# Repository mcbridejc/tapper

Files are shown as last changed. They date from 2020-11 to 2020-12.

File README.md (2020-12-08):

# Tapper

A flexible way to build well-packaged touch-screen based devices with 
STM32 nucleo-32 boards. 

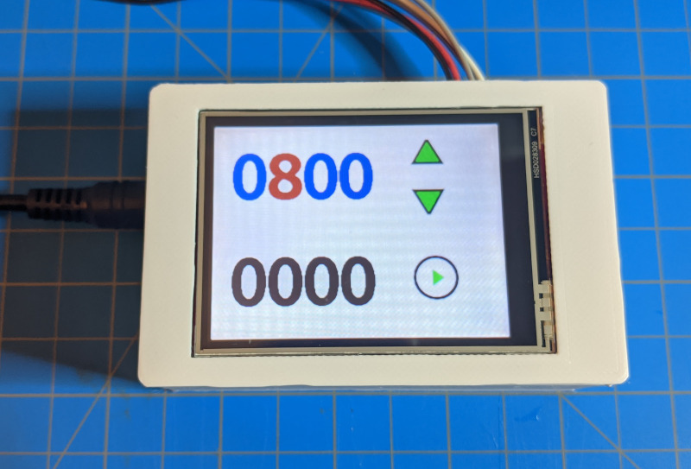
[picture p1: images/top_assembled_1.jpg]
Tapper


## Introduction

I wanted a quick and easy way to bring up any kind of touch screen based 
device that wasn't a one-off jumble of wires and/or breadboards.
My main requirements are that it needs a case, and it needs to be connecterized. 
I wanted to keep some flexibility though, because you can't quite predict which 
pins you need to wire out to which connectors next time, and you might need a 
bit of extra circuitry. 

On tapper, the connector IOs are connected only to test points. 
The MCU pins are also wired out to test points. To customize for a particular 
application, just solder jumper wires to connect as neded. 
There's also a small amount of 0.1" pitch hole array for prototyping; enough 
to fit a couple chips and discretes, e.g. using SMT to DIP adapters.

PDF schematic can be found [here](pcb/Tapper_rev2_schematic.pdf).

Bill of materials can be found [here](pcb/BOM.xlsx).

Gerbers can be found under github releases, if you want to build one!

## Powering 

The Tapper has a 5.5x2.1mm barrel connector for power input (7V min, up to about 
12-ish V<sup>[1](#maxvolts)</sup>), or, optionally it can be powered via the USB connector if you
don't need any voltage higher than 5V. 
For my initial application I needed a higher voltage for motor control, so
the tapper includes a linear regulator to generare the 5V input for the nucleo.
Thanks to the diode-or on the nucleo-32 board, it is safe to provide both USB 
power and an extra VIN. 

## Connectors

There are three 6-pin JST SH connectors. [Pre-made pigtails](https://www.digikey.com/en/products/detail/trinamic-motion-control-gmbh/CABLE-PH06/9381902) 
can be used to connect to these. Each connector has a ground pin, a power pin 
which can be connected to 3.3V, 5V, or VIN -- selected by solder bridge -- and
four IO pins which are connected to testpoints. These can be connected by 
wires soldered to either the MCU breakout testpoints or to 
a circuit on the prototype pad array.

## STM32 Development Board

Tapper is designed for the [Nucleo-G431KB](https://www.st.com/en/evaluation-tools/nucleo-g431kb.html),
but since all of the Nucleo-32 boards have a compatible pinout -- at least 
I'm pretty sure they do, double check -- it should be easy to use a different
family of STM32 MCU. The ST Nucleo boards come with a built-in ST-LINK USB
programmer/debugger, which also provides a virtual COM port connected to the
USART on your target device.

### Nucleo board modifications

**Important: You probably need to modify your Nucleo board!**

Remove SB2 and SB3. These short PA15 to PA6 and PB7 to PA6 -- why ST thought
it was a good idea to ship development boards with jumpers shorting their 
IOs is beyond me, but removing them is the first thing I do on every nucleo 
board.

Short SB11. This connects PF1 to the IO header, and is needed to drive the 
display DC pin. Without shorting this solder bridge, the display will not
update.

## Enclosure

The enclosure can be 3D printed. Heated threaded inserts are used to provide
solid mounting points for the electronicson the top cover. See the 
[Bill of Materials](pcb/BOM.xls). It uses flexible retaining clips to hold
the two parts of the enclosure together, and this works....OK. If the print 
isn't dialed in just right, the top cover might not sit perflectly tight; 
functional but disappointing. At some point, I may redesign it to use some 
longer screws that go all the way through the enclosure. It was the first 
time I tried printing such a thing, and it was a worthwhile experiment, anyway.

### Top Model

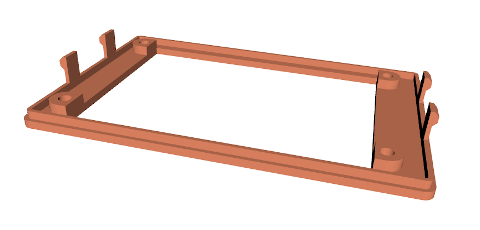
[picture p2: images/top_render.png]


[3D Model - STEP](enclosure/tapper_enclosure_top.step)

[3D Model - STL](enclosure/tapper_enclosure_top.stl)

### Bottom Model

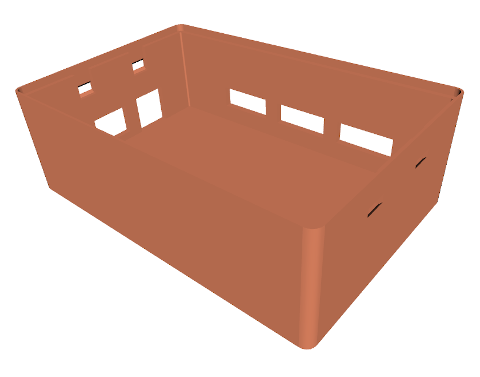
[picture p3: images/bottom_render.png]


[3D Model - STEP](enclosure/tapper_enclosure_bottom.step)

[3D Model - STL](enclosure/tapper_enclosure_bottom.stl)

## Example Software

This [spincoater controller](https://github.com/mcbridejc/spincoater-controller) project uses the Tapper board, and provides an
example software project using the [modm](https://modm.io) C++ peripheral library, which
I highly recommend for STM32 projects.

## Photos

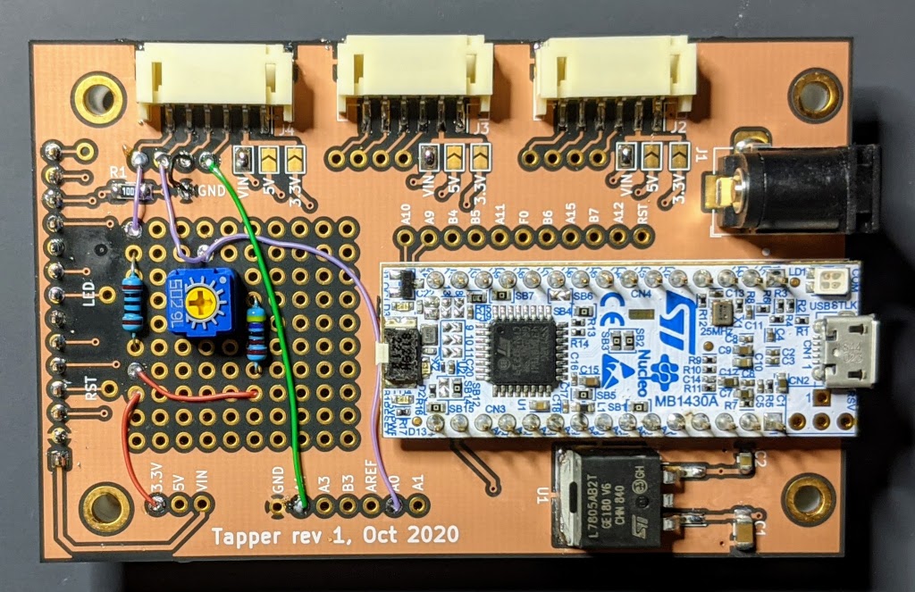
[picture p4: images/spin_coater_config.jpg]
Bareboard with spincoater wiring


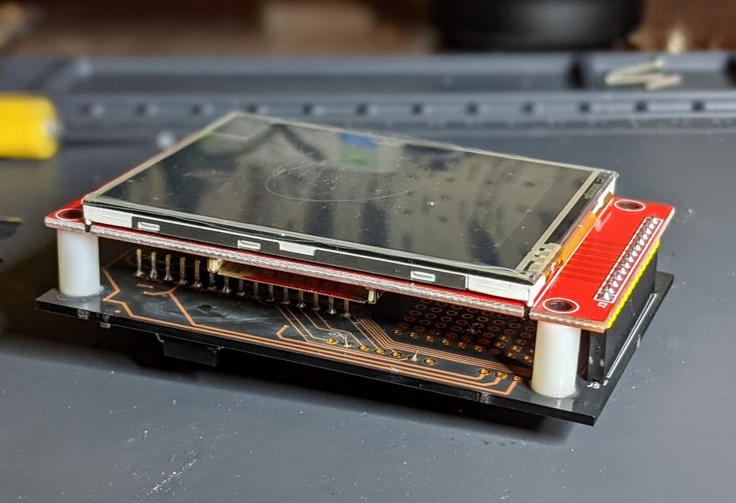
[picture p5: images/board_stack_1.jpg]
Board stackup with display


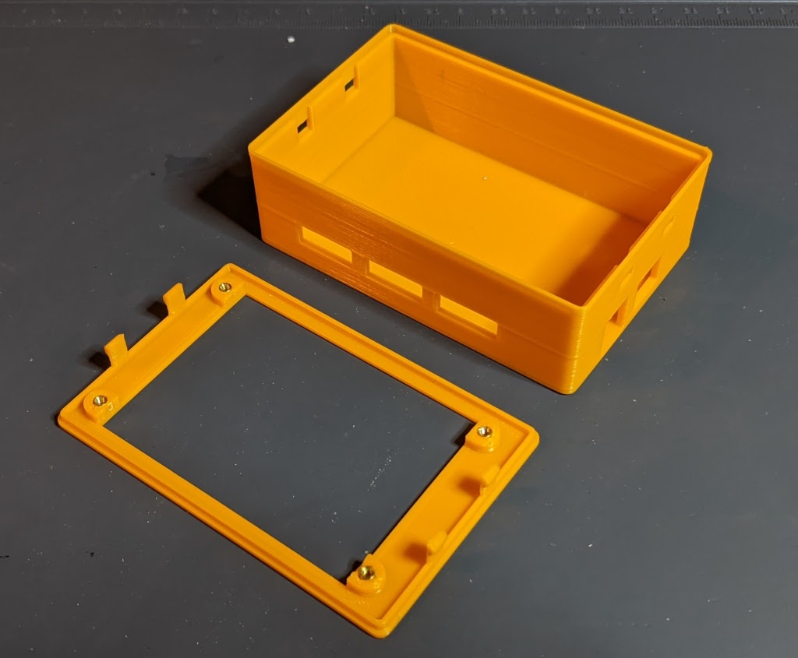
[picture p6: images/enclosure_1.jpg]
Enclosure


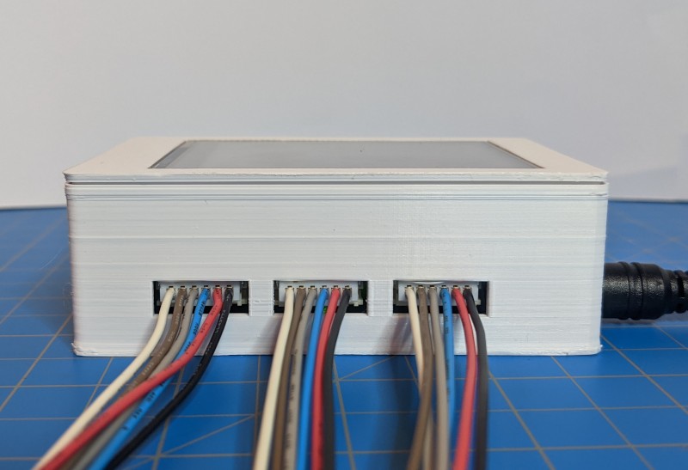
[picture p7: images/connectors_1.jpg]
IO connectors


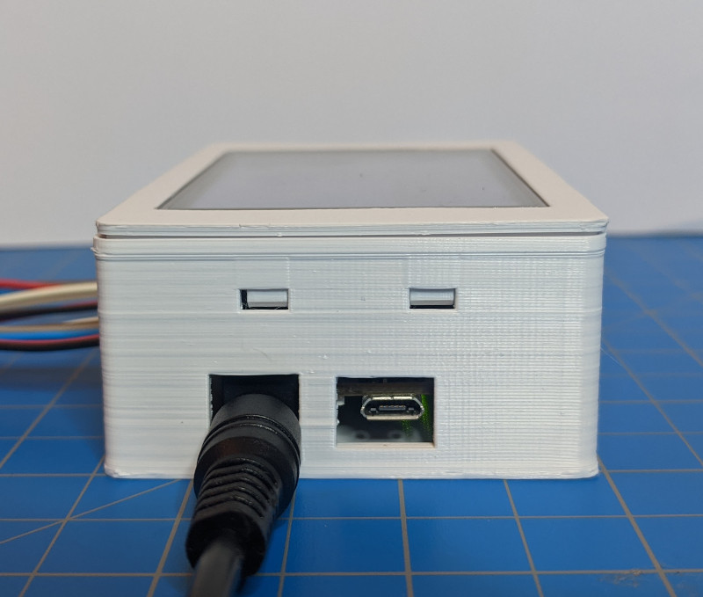
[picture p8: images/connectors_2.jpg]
Power and USB connectors


## Revision History

### Revision 2 (Nov 2020)

Fix a few mistakes, including: 

- Add pull-up to display reset pin
- Power connection points labeled wrong in silkscreen (3.3V and VIN swapped, yikes)
- One mounting hole position off by 0.5mm

### Revision 1 (Oct 2020)

First prototype design. 

# Footnotes

<b id="maxvolts">1:</b>The max voltage will be limited by the thermal dissipation of the 
linear regulator, and will depend on how much power is drawn from the 5V rail. If 
it gets too hot to touch, it might be time to consider lowering your input voltage!

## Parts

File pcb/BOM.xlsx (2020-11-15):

Digikey
RefDes | Mfg Part Number | Qty | Description | Unit Cost | Total Cost
J1 | 839-1514-ND‎ | 1 | Barrel Jack | $0.97 | $0.97
J2, J3, J4 | S6B-PH-SM4-TB(LF)(SN) | 3 | JST PH connectors | $0.72 | $2.16
J5 | PPPC141LFBN-RC | 1 | 14 pos header, female | $0.95 | $0.95
U1 | L7805ABD2T-TR | 1 | Linear regulator, 5V | $0.66 | $0.66
C1 | CL31A106KBHNNNE | 1 | 10uF 1206 | $0.25 | $0.25
C2 | CL21B105KAFNNNG | 1 | 1uF 805 | $0.03 | $0.03
H1-H4 | 960110042 | 4 | Spacers, 11mm | $0.25 | $1.00
R1-R2 | ERJ-8ENF1002V | 2 | 10k 1206 | $0.03 | $0.06
A1 | Nucleo-G431KB | 1 | STM32 Dev board | $13.00 | $13.00
 | 1460-1297-ND | 3 | 6-pin PH pigtail | $1.06 | $3.18
 |  |  |  |  | $0.00
McMaster | 1460-1297-ND |  |  |  | $0.00
NA | 94459A110 | 4 | Heat inserts M2 | $0.17 | $0.68
 | 92000A022 | 4 | m2x16mm screw | $0.07 | $0.28
 |  |  |  |  | $0.00
Amazon |  |  |  |  | $0.00
NA | Hiletgo ILI9341 2.8” | 1 | LCD display with touch panel | $14.00 | $14.00
Oshpark
NA | PCBs | 1 | basic oshpark price | 12.33333333 | $12.33
 |  |  |  | Total: | $49.55

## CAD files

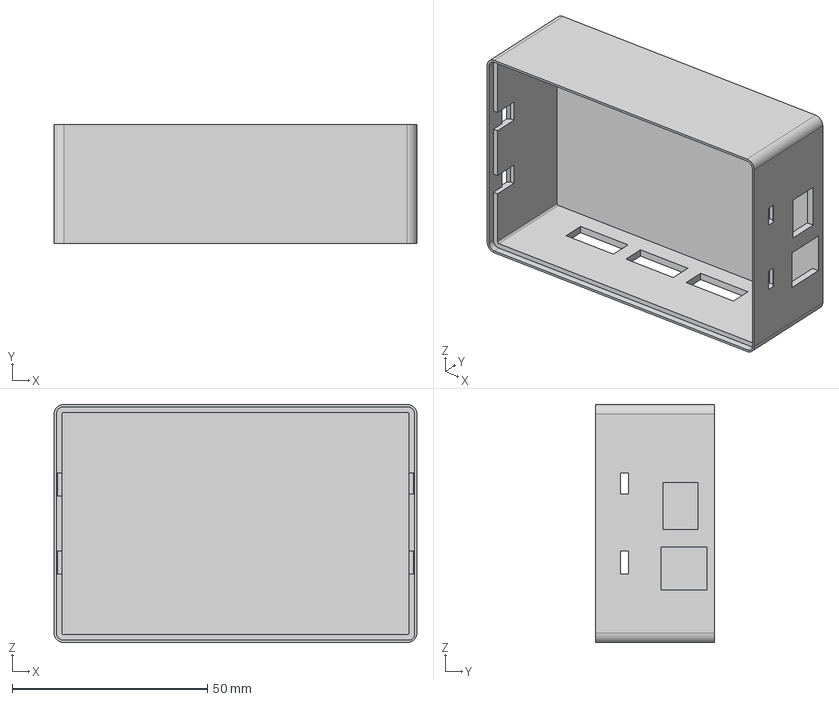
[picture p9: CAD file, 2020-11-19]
enclosure/tapper_enclosure_bottom.step
93.0 x 30.6 x 61.0 mm

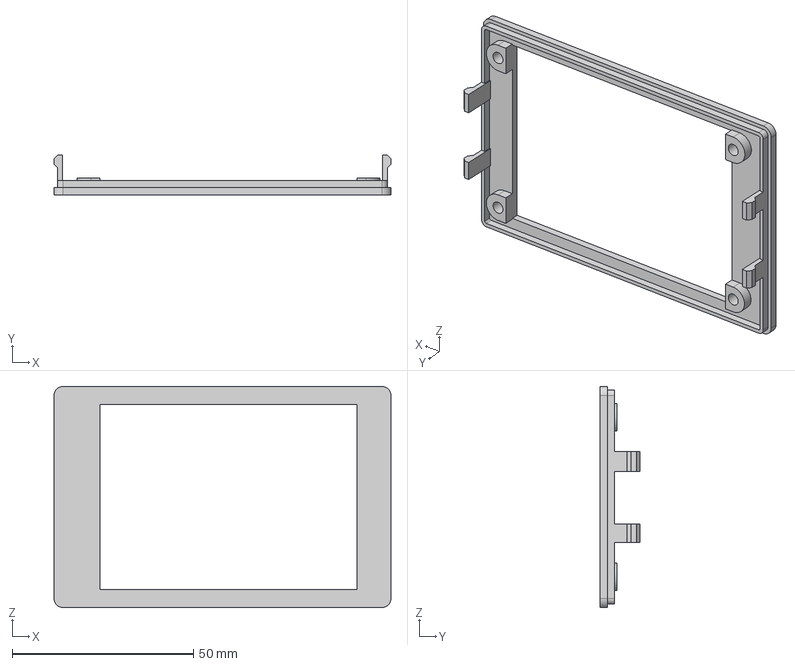
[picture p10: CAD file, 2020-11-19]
enclosure/tapper_enclosure_top.step
93.0 x 11.0 x 61.0 mm

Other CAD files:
enclosure/tapper_enclosure_bottom.stl
enclosure/tapper_enclosure_top.stl

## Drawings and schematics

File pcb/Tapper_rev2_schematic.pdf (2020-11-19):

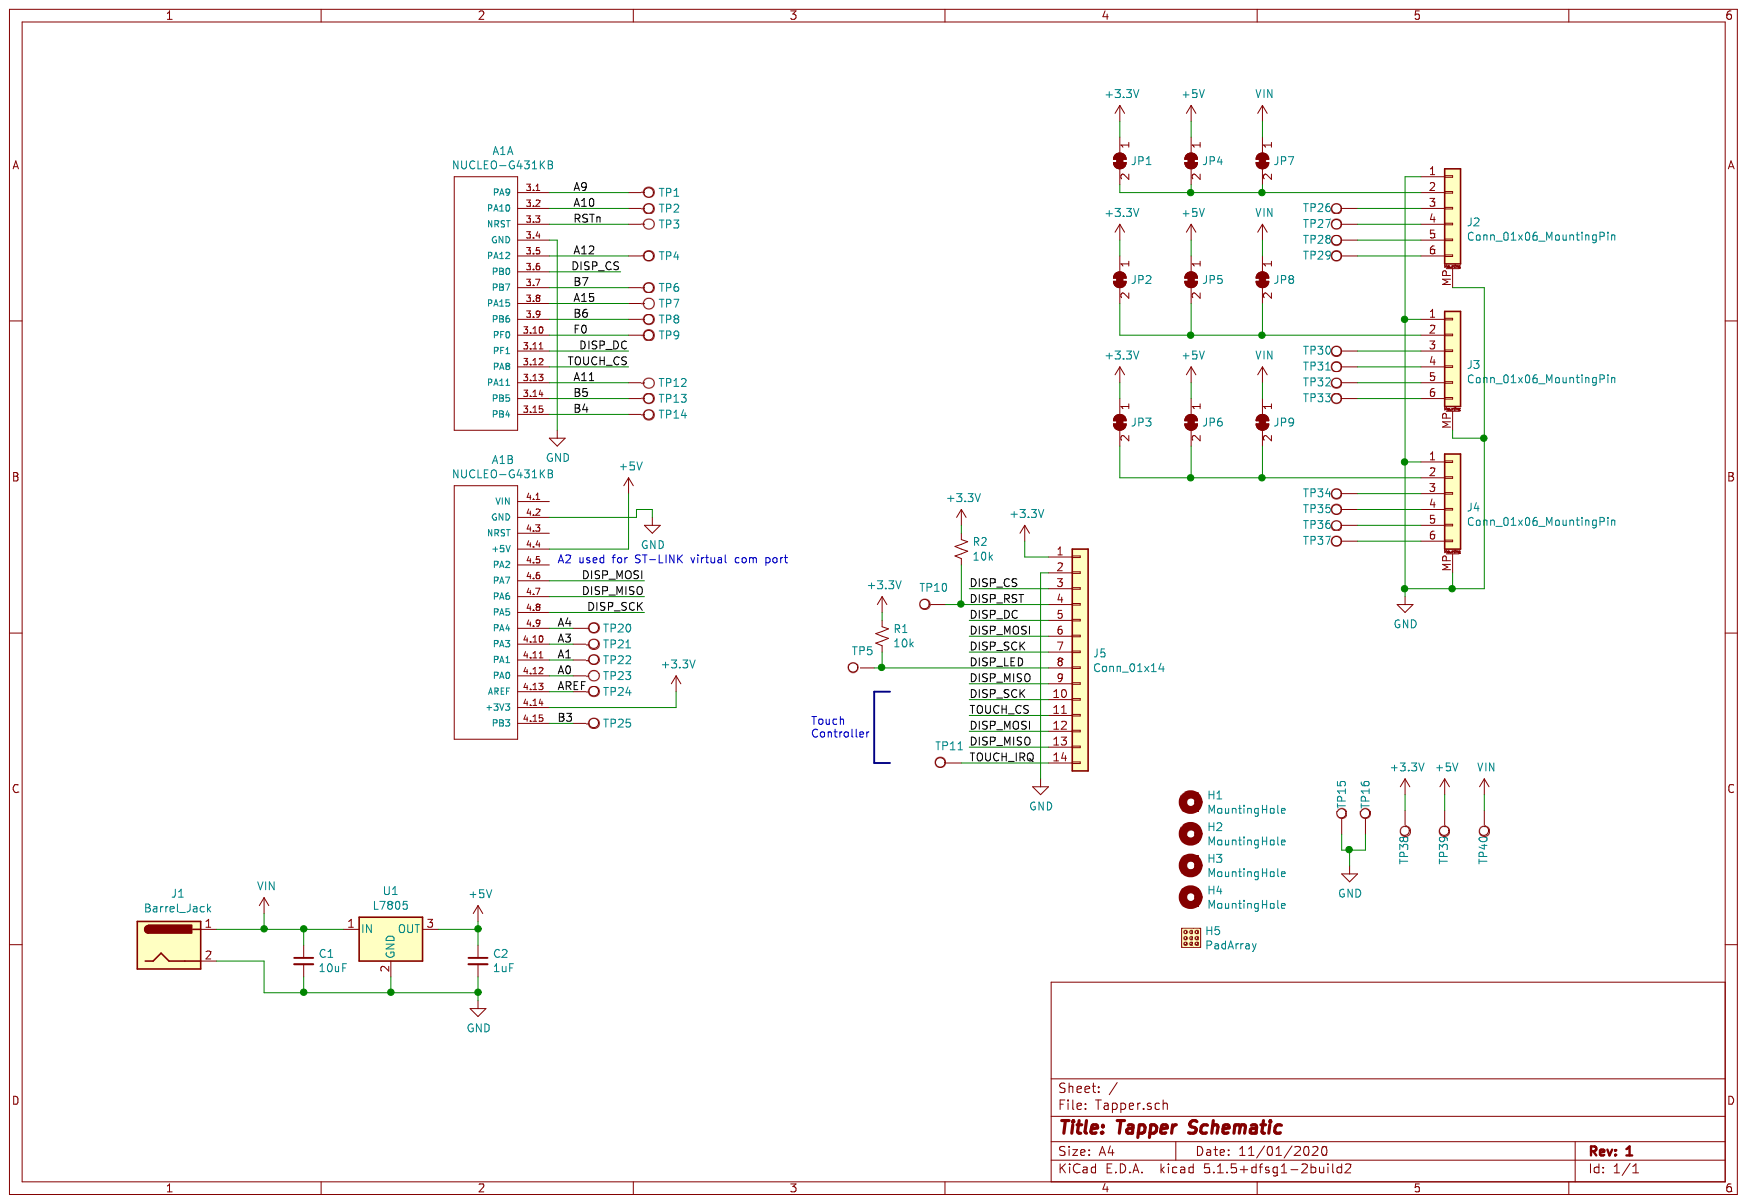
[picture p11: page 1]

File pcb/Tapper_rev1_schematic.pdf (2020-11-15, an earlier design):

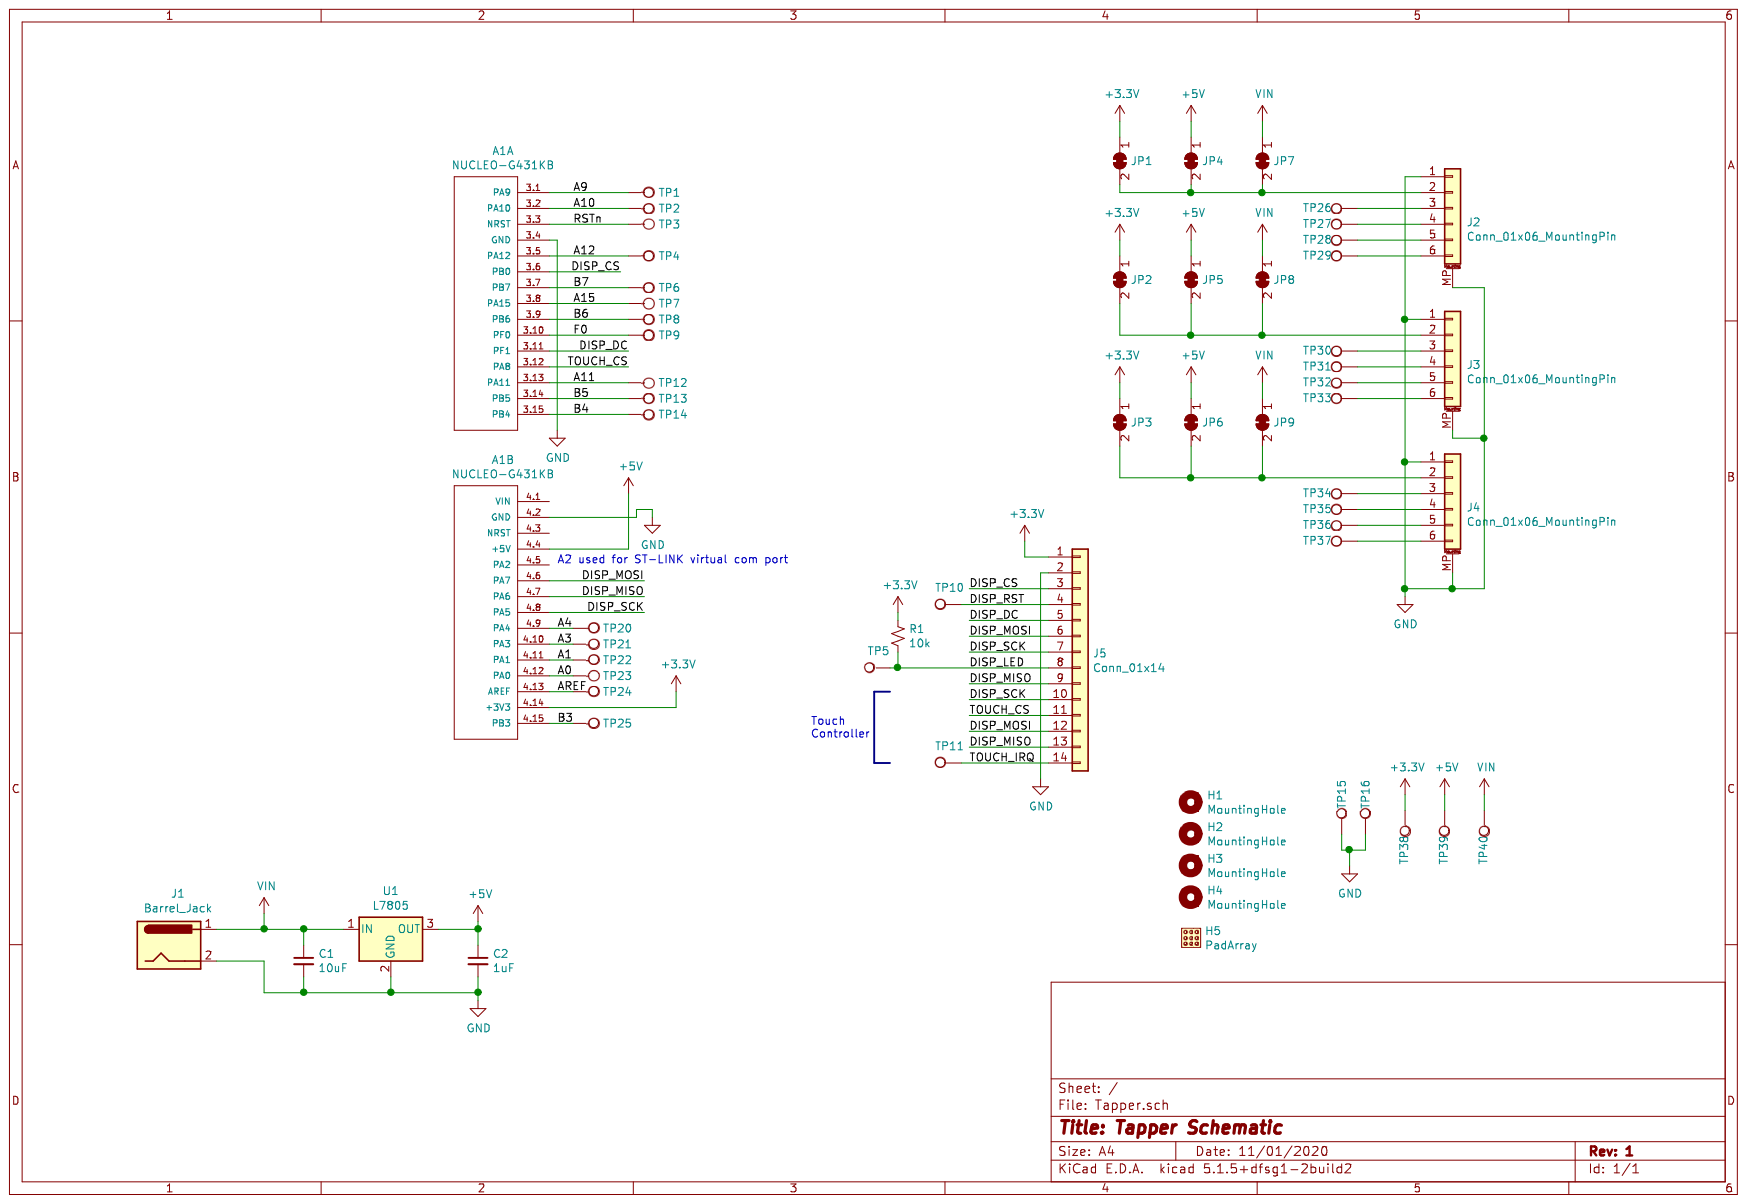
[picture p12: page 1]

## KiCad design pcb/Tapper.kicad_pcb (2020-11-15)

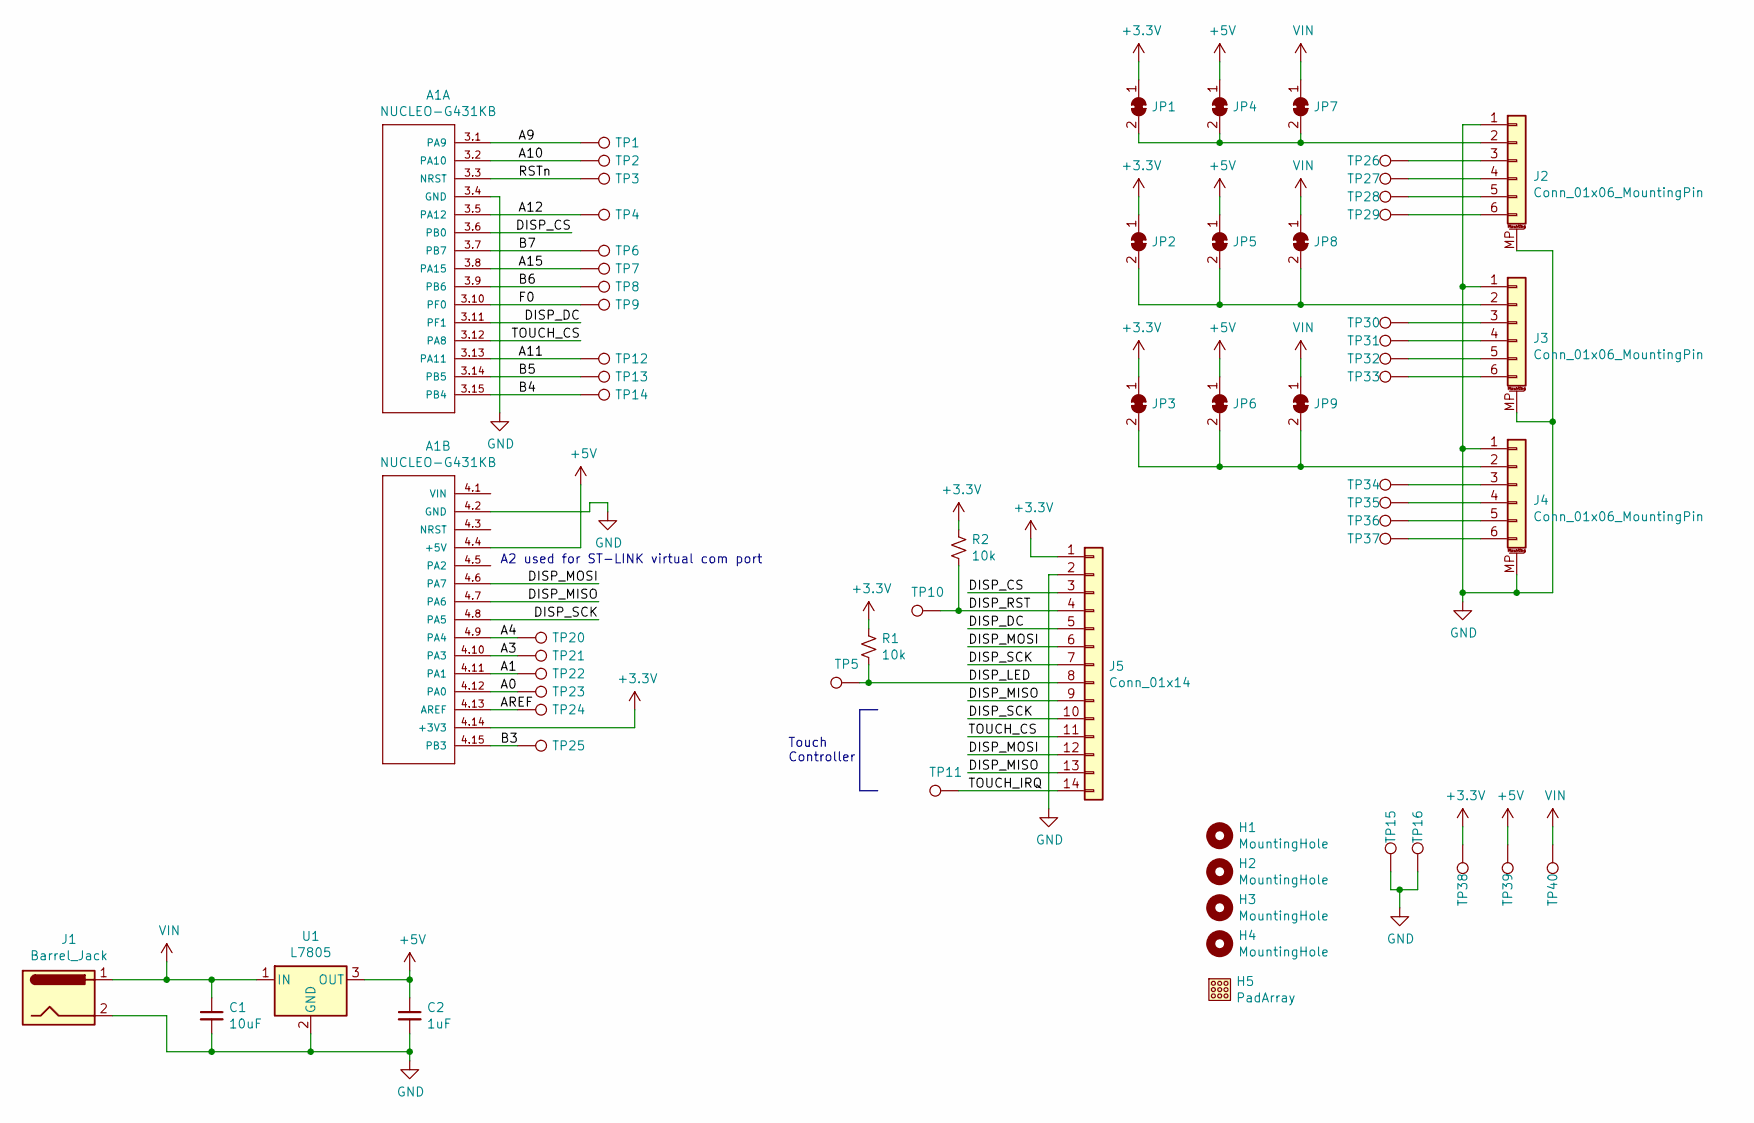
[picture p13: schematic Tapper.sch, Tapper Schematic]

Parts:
A1: NUCLEO-G431KB; MODULE_NUCLEO-32
C1: 10uF; C_1206_3216Metric_Pad1.42x1.75mm_HandSolder; Mfg Part Number CL31A106KBHNNNE
C2: 1uF; C_0805_2012Metric_Pad1.15x1.40mm_HandSolder; Mfg Part Number CL21B105KAFNNNG
H1, H2, H3, H4: MountingHole; SpacerPad
H5: PadArray; ProtoArray_10x10_2.54mm
J1: Barrel_Jack; BarrelJack_Horizontal
J2, J3, J4: Conn_01x06_MountingPin; JST_PH_S6B-PH-SM4-TB_1x06-1MP_P2.00mm_Horizontal
J5: Conn_01x14; PinHeader_1x14_P2.54mm_Vertical
JP1, JP2, JP3, JP4, JP5, JP6, JP7, JP8, JP9: SolderJumper_2_Bridged; SolderJumper-2_P1.3mm_Open_TrianglePad1.0x1.5mm
R1, R2: 10k; R_1206_3216Metric_Pad1.42x1.75mm_HandSolder
TP1, TP2, TP3, TP4, TP5, TP6, TP7, TP8, TP9, TP10, TP11, TP12, TP13, TP14, TP15, TP16, TP20, TP21, TP22, TP23, TP24, TP25, TP26, TP27, TP28, TP29, TP30, TP31, TP32, TP33, TP34, TP35, TP36, TP37, TP38, TP39, TP40: TP; SolderPoint
U1: L7805; TO-263-2; Mfg Part Number L7805ABD2T-TR

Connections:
+3V3: A1.4.14 (+3V3), J5.1, JP1.1 (A), JP2.1 (A), JP3.1 (A), R1.1, R2.1, TP38.1
+5V: A1.4.4 (+5V), C2.1, JP4.1 (A), JP5.1 (A), JP6.1 (A), TP39.1, U1.3 (OUT)
/A0: A1.4.12 (PA0), TP23.1
/A1: A1.4.11 (PA1), TP22.1
/A3: A1.4.10 (PA3), TP21.1
/A4: A1.4.9 (PA4), TP20.1
/A9: A1.3.1 (PA9), TP1.1
/A10: A1.3.2 (PA10), TP2.1
/A11: A1.3.13 (PA11), TP12.1
/A12: A1.3.5 (PA12), TP4.1
/A15: A1.3.8 (PA15), TP7.1
/AREF: A1.4.13 (AREF), TP24.1
/B3: A1.4.15 (PB3), TP25.1
/B4: A1.3.15 (PB4), TP14.1
/B5: A1.3.14 (PB5), TP13.1
/B6: A1.3.9 (PB6), TP8.1
/B7: A1.3.7 (PB7), TP6.1
/DISP_CS: A1.3.6 (PB0), J5.3
/DISP_DC: A1.3.11 (PF1), J5.5
/DISP_LED: J5.8, R1.2, TP5.1
/DISP_MISO: A1.4.7 (PA6), J5.9, J5.13
/DISP_MOSI: A1.4.6 (PA7), J5.6, J5.12
/DISP_RST: J5.4, R2.2, TP10.1
/DISP_SCK: A1.4.8 (PA5), J5.7, J5.10
/F0: A1.3.10 (PF0), TP9.1
/RSTn: A1.3.3 (NRST), TP3.1
/TOUCH_CS: A1.3.12 (PA8), J5.11
/TOUCH_IRQ: J5.14, TP11.1
GND: A1.3.4 (GND), A1.4.2 (GND), C1.2, C2.2, J1.2, J2.1, J2.MP (MountPin), J3.1, J3.MP (MountPin), J4.1, J4.MP (MountPin), J5.2, TP15.1, TP16.1, U1.2 (GND)
unnamed: J2.2, JP1.2 (B), JP4.2 (B), JP7.2 (B)
unnamed: J2.3, TP26.1
unnamed: J2.4, TP27.1
unnamed: J2.5, TP28.1
unnamed: J2.6, TP29.1
unnamed: J3.2, JP2.2 (B), JP5.2 (B), JP8.2 (B)
unnamed: J3.3, TP30.1
unnamed: J3.4, TP31.1
unnamed: J3.5, TP32.1
unnamed: J3.6, TP33.1
unnamed: J4.2, JP3.2 (B), JP6.2 (B), JP9.2 (B)
unnamed: J4.3, TP34.1
unnamed: J4.4, TP35.1
unnamed: J4.5, TP36.1
unnamed: J4.6, TP37.1
VIN: C1.1, J1.1, JP7.1 (A), JP8.1 (A), JP9.1 (A), TP40.1, U1.1 (IN)

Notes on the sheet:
A2 used for ST-LINK virtual com port
Touch Controller

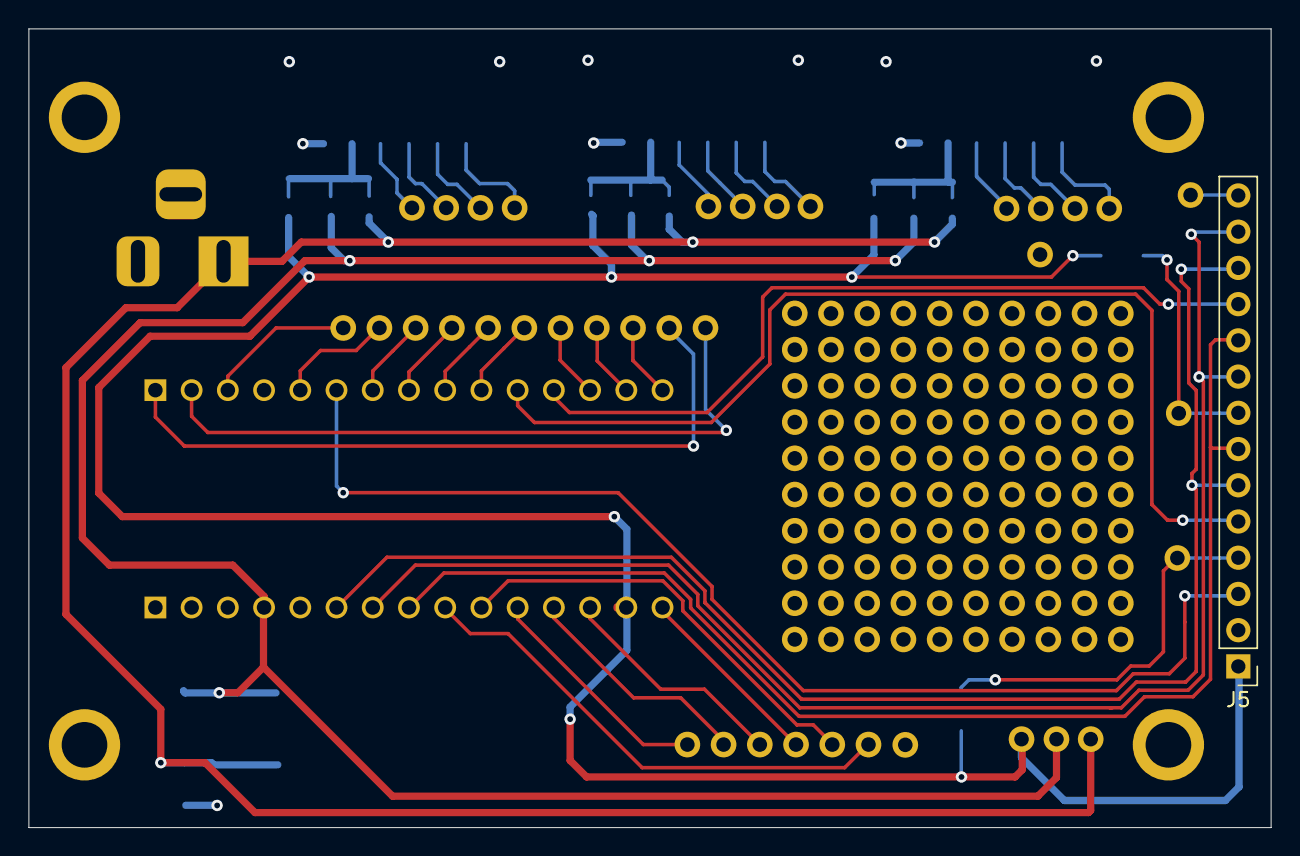
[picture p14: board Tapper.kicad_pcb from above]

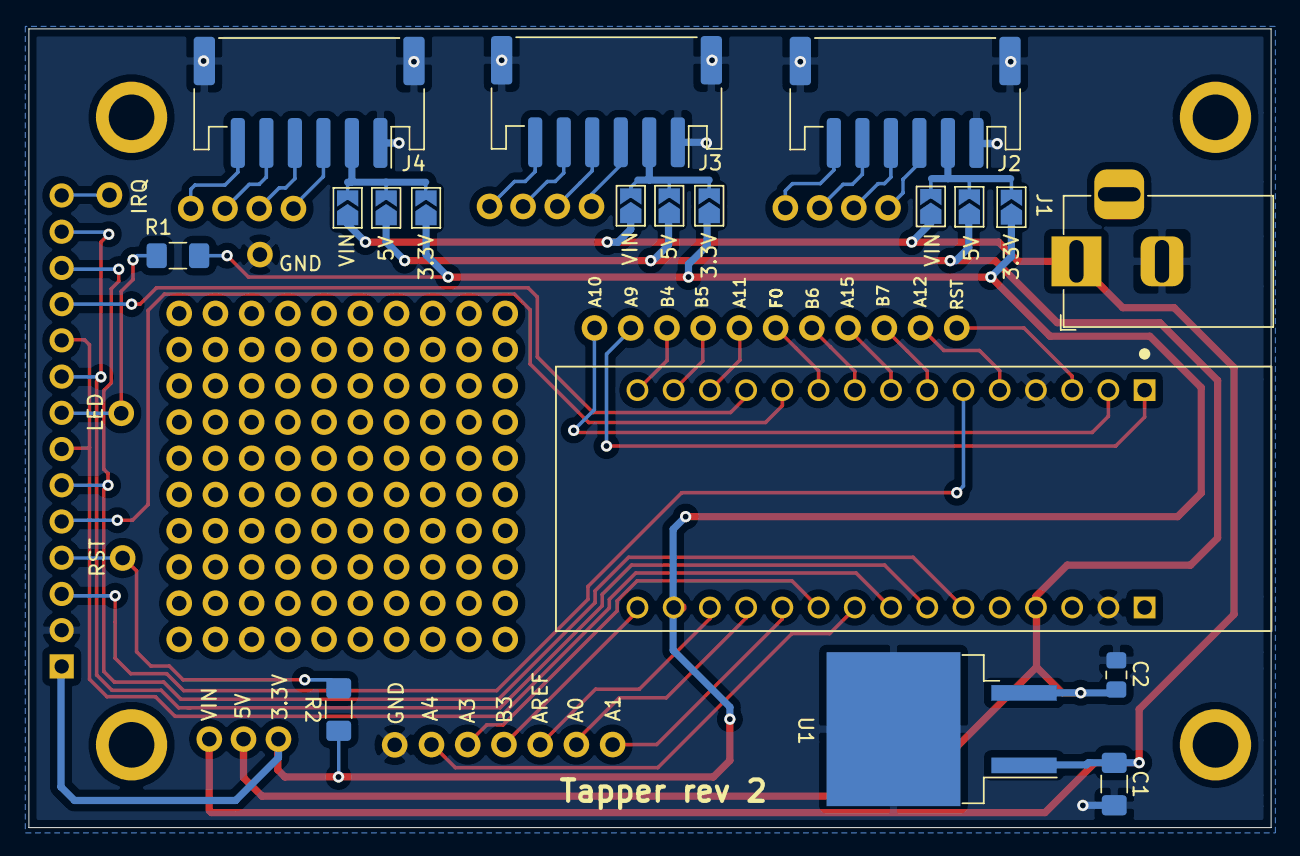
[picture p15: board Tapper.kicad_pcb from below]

Board: 2 copper layers, 87.1 x 56.0 mm, 62 parts (19 on the bottom side), 45 nets.

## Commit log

2020-11-15 Rev 1 PCB files
    [BOM.xlsx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]
2020-11-15 Add PDF schematic for rev1
2020-11-15 Fix errors in rev1
    [BOM.xlsx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]
2020-11-19 Add enclosure models
    [tapper_enclosure_bottom.step, tapper_enclosure_bottom.stl, tapper_enclosure_top.step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]
2020-11-19 Add rev2 gerbers
    [Tapper-B_Cu.gbr, Tapper-B_Mask.gbr, Tapper-B_SilkS.gbr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]
2020-11-19 Add rev2 schematic PDF
2020-11-19 Add note about nucleo board modifications
